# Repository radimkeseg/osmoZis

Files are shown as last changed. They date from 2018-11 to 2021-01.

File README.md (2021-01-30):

# OsmoZis v2 - osmóza - neinvazivní vysoušení vlhkého zdiva

... in other languages [english](README.en.md)

Potřebujete se zbavit vzlínající vlhkosti ve vašem domě? Typicky u starého domu s problematickou izolací základů?

Bez zbytečných průtahů a přílišné teorie, je jistá šance, že zařízení, které je zde popsané Vám může pomoci.
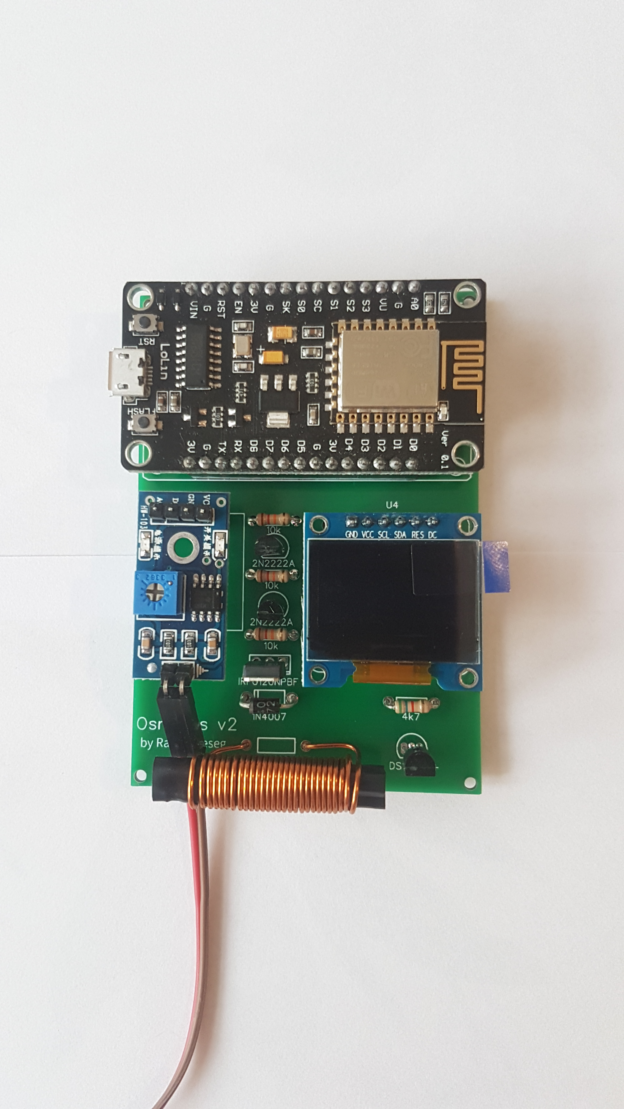
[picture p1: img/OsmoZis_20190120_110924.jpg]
OsmoZis v2


# Jak to funguje?
Zjednodušeně řečeno, toto zařízení generuje nízko frekvenční špičky, které eliminují síly které umožňuje vodnímu roztoku ve zdi překonat gravitaci a vyhrát nad silou, které způsobuje vzlínání, a voda se vrátí zpět do země.

Může to znít jako kouzlo, nicméně experimentálně byla funkčnost úspěšně ověřena.

Pokud se chcete dozvědět více detailů od expertů, určitě najdete na internetu spoustu článku a videí které by Vám mohli pomoci porozumět principu elektro-osmozy. Zajímavé video může být například v následujícím odkazu https://www.youtube.com/watch?v=hDw9_C7s-Mk.

# Je možné taková zařízení koupit?
Samozřejmě že ano, jen hledejte OSMO-něco ... jen jsou tato zařízení příliš drahá a jediné, jak člověk pozná že něco dělají je svítící dioda bez další možnosti, jak si průběžně ověřit, že zařízení funguje.

Toto je levné zařízení, které stojí jen zlomek ceny (asi 200 - 500kč za součástky dle toho, kde je koupíte) naproti tomu co je nabízeno na trhu (20000 - 50000 kč), ale poskytuje mnohem více funkcí:
* na displeji je možné vidět aktuální vlhkost
* dále i aktuální teplotu
* zařízení se dá připojit na wifi
  * kde dále vidíte jeho adresu
  * a aktuální čas
* s dalšími nastaveními
  * časová zóna
  * a odesílání dat na cloud (www.thinkgspeak.com) kde můžete vidět grafy vlhkosti a teploty online každý 10 minut standardně (nebo si interval nastavit dle osobních preferencí)

# Co potřebuji na to si zařízení vyrobit?
v adresáři ["img"](img), najdete návrh obvodu zařízení, dále výrobní data pro desku a další obrázky, které vám pomohou celé zařízení vytvořit.

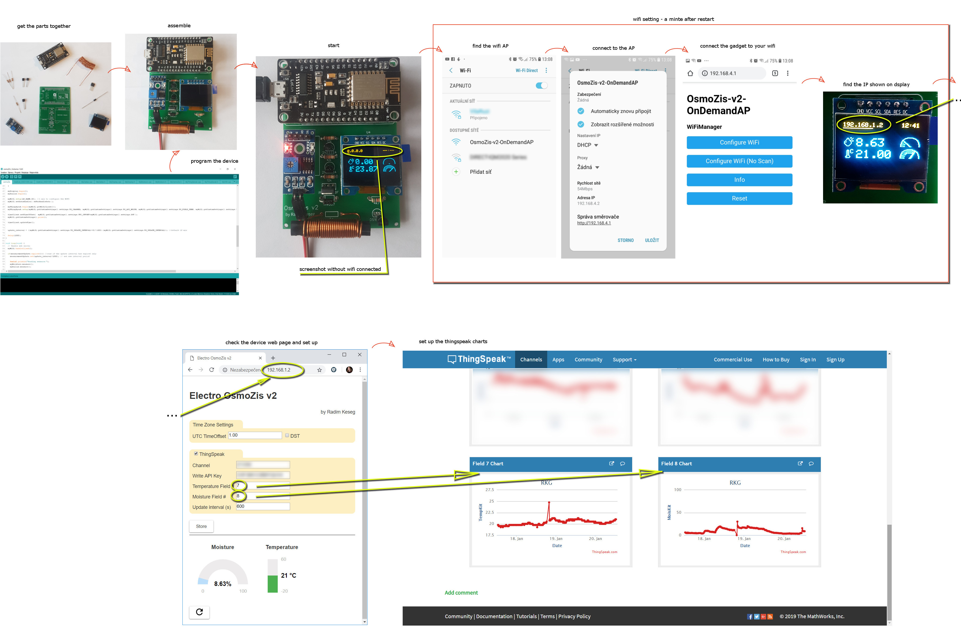
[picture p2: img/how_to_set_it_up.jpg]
setup


# Jak zařízení oživit?
v tomto adresáři najdete kód programu, na který se můžete podívat a případně jej upravit, pokud nechcete jen jej nahrajte do ESP přímo.

Pokud chcete zkoumat kód, je třeba stáhnout některé další knihovny, jejichž seznam najdete níže.

1. <OneWire.h> 
2. <DallasTemperature.h>

3. <SPI.h>
4. <Wire.h>
5. <Adafruit_GFX.h>
6. "Adafruit_SSD1306.h"

7. <Interval.h>
8. <ThingSpeak.h>

9. <WifiManager.h> (tzapo)

10. ESP8266 desku a knihovny k ní

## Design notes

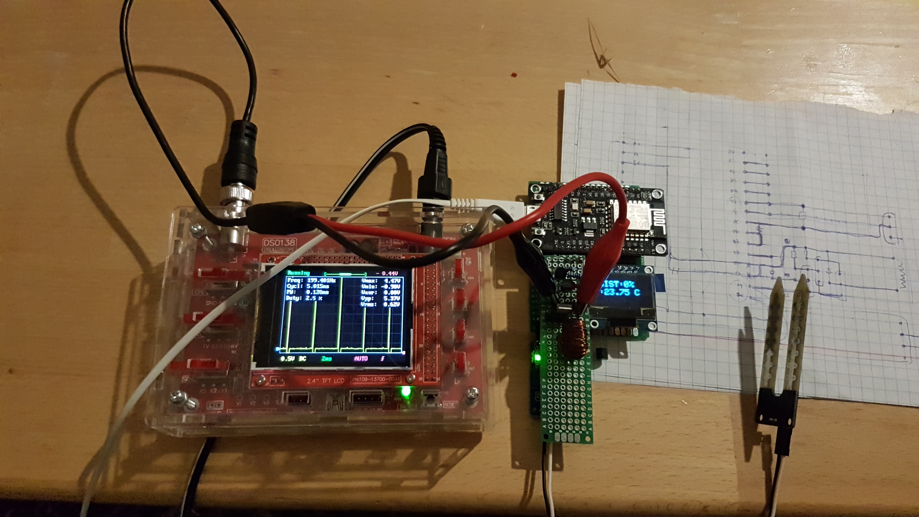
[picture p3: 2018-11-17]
img/prototype_20181117_184112.jpg

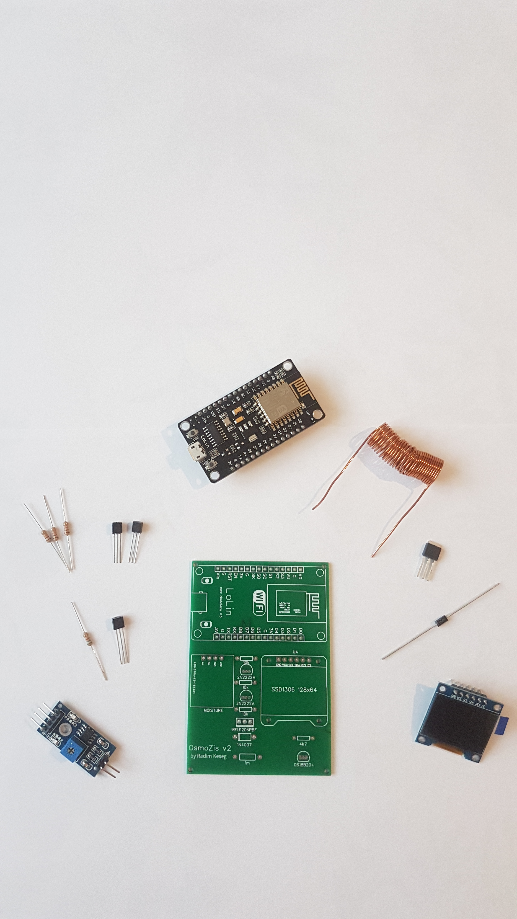
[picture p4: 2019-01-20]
img/OsmoZis_20190120_093138.jpg

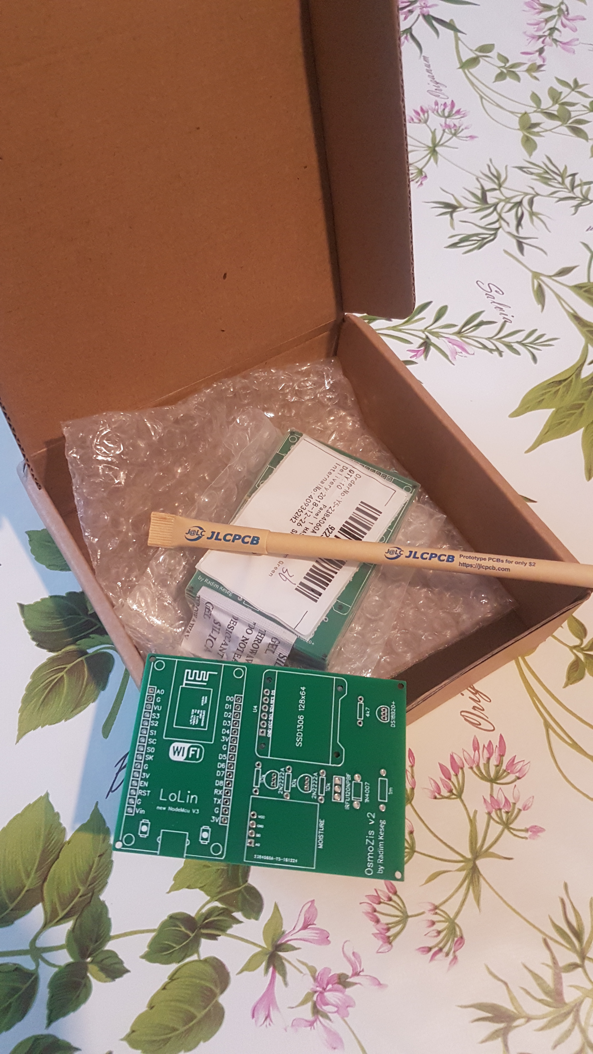
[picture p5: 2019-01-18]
img/JLCPCB_20190118_084525.jpg

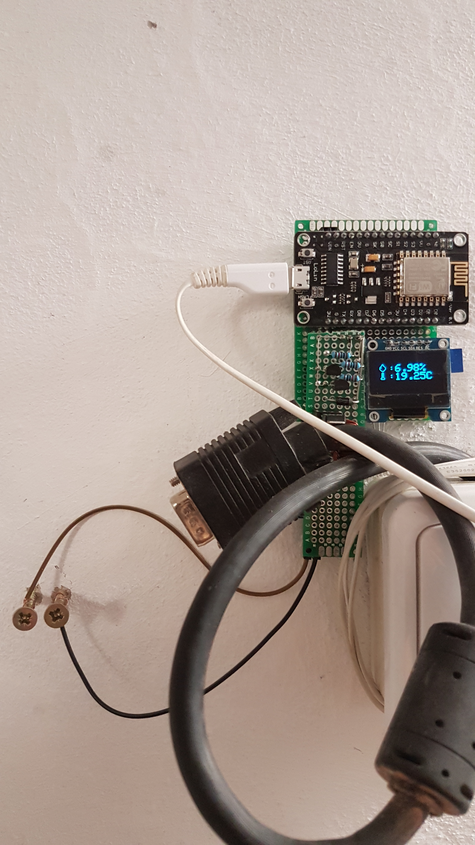
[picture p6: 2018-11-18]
img/prototype_20181118_135021.jpg

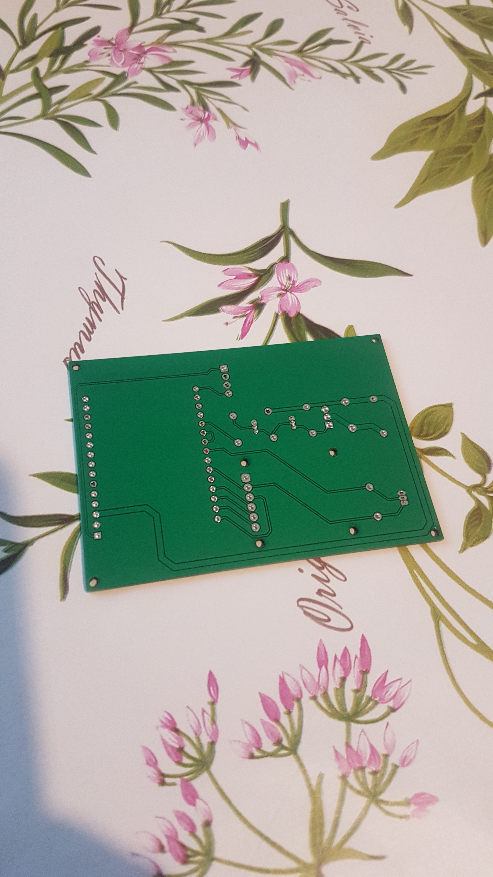
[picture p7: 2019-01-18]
img/JLCPCB_20190118_084754.jpg

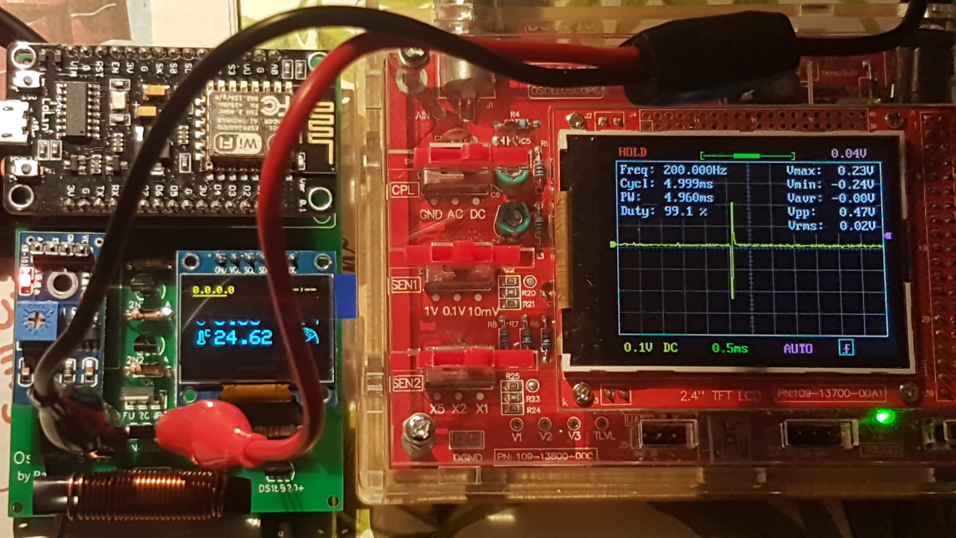
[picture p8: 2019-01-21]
img/short_duty_cycle.jpg

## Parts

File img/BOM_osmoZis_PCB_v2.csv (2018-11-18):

ID | Name | Designator | Footprint | Quantity | Manufacturer Part | Manufacturer | Supplier | Supplier Part | Mounted
1 | NODEMCU_V1_ESP12E | U1 | ESP12E_DEVKIT-V1 | 1 | ? |  |  |  | Yes
2 | DS18B20+ | U3 | TO-92(TO-92-3) | 1 | DS18B20+ | MAXIM | LCSC | C9753 | Yes
3 | 4k7 | R1 | AXIAL-0.3 | 1 | ? |  |  |  | Yes
4 | 10k | R2,R3,R4 | AXIAL-0.3 | 3 | ? |  |  |  | Yes
5 | 2N2222A | Q1,Q2 | TO-92 | 2 | ? |  |  |  | Yes
6 | IRFU120NPBF | Q3 | TO-251(I-PAK) | 1 | IRFU120NPBF | IR | LCSC | C3025 | Yes
7 | 1N4007 | D1 | DO-41 | 1 | 1N4007 | STARSEA | LCSC | C84641 | Yes
8 | 1m | L1 | AXIAL-0.4 | 1 | ? |  |  |  | Yes
9 | breakout | MOISTURE | SPARKFUN SHT15 | 1 | ? |  | SparkFun | 12587 | Yes
10 | SSD1306_6PIN | U4 | SSD1306_6_PIN | 1 | New SchematicLib |  |  | undefined | Yes

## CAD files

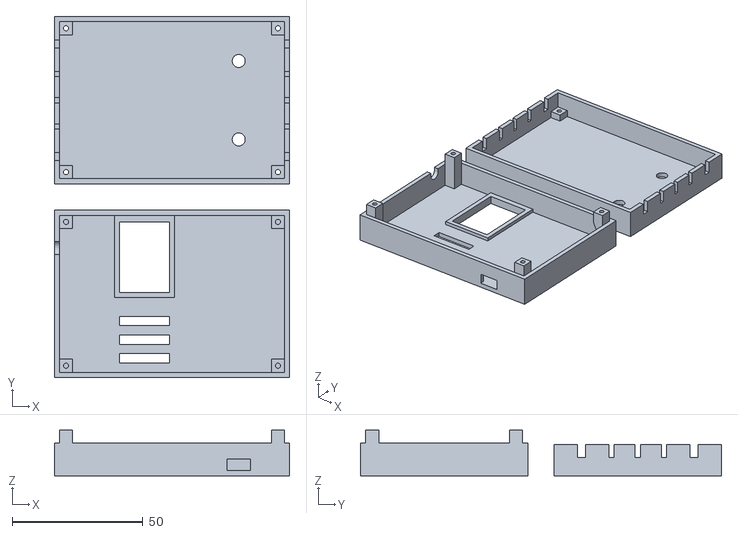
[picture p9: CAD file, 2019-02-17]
img/Osmozis V2.1.stl
90.0 x 138.0 x 17.5

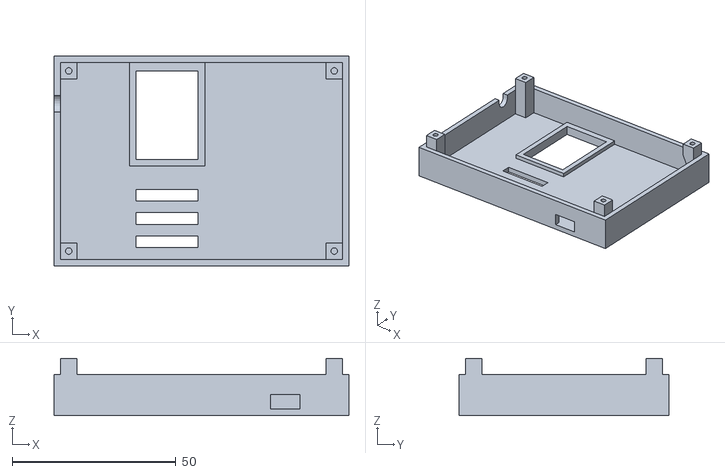
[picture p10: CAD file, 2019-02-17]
img/Osmozis V2.1 top.stl
90.0 x 64.0 x 17.5

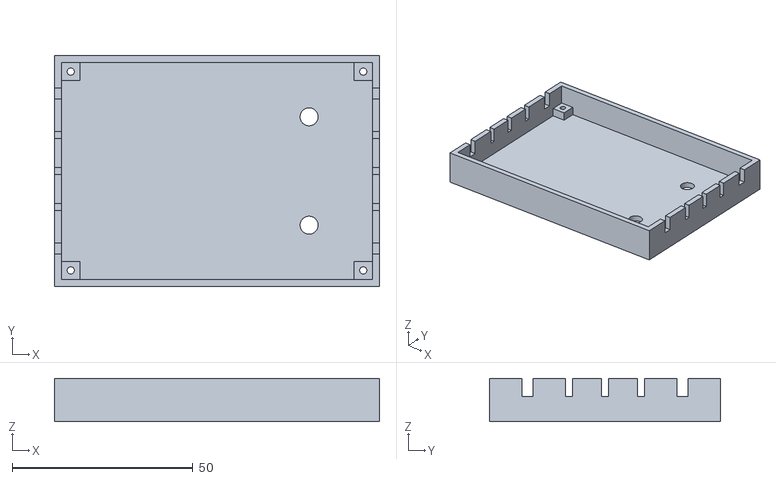
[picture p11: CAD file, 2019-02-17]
img/Osmozis V2.1 bottom.stl
90.0 x 64.0 x 12.0

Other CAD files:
img/Osmozis V2.1.skp

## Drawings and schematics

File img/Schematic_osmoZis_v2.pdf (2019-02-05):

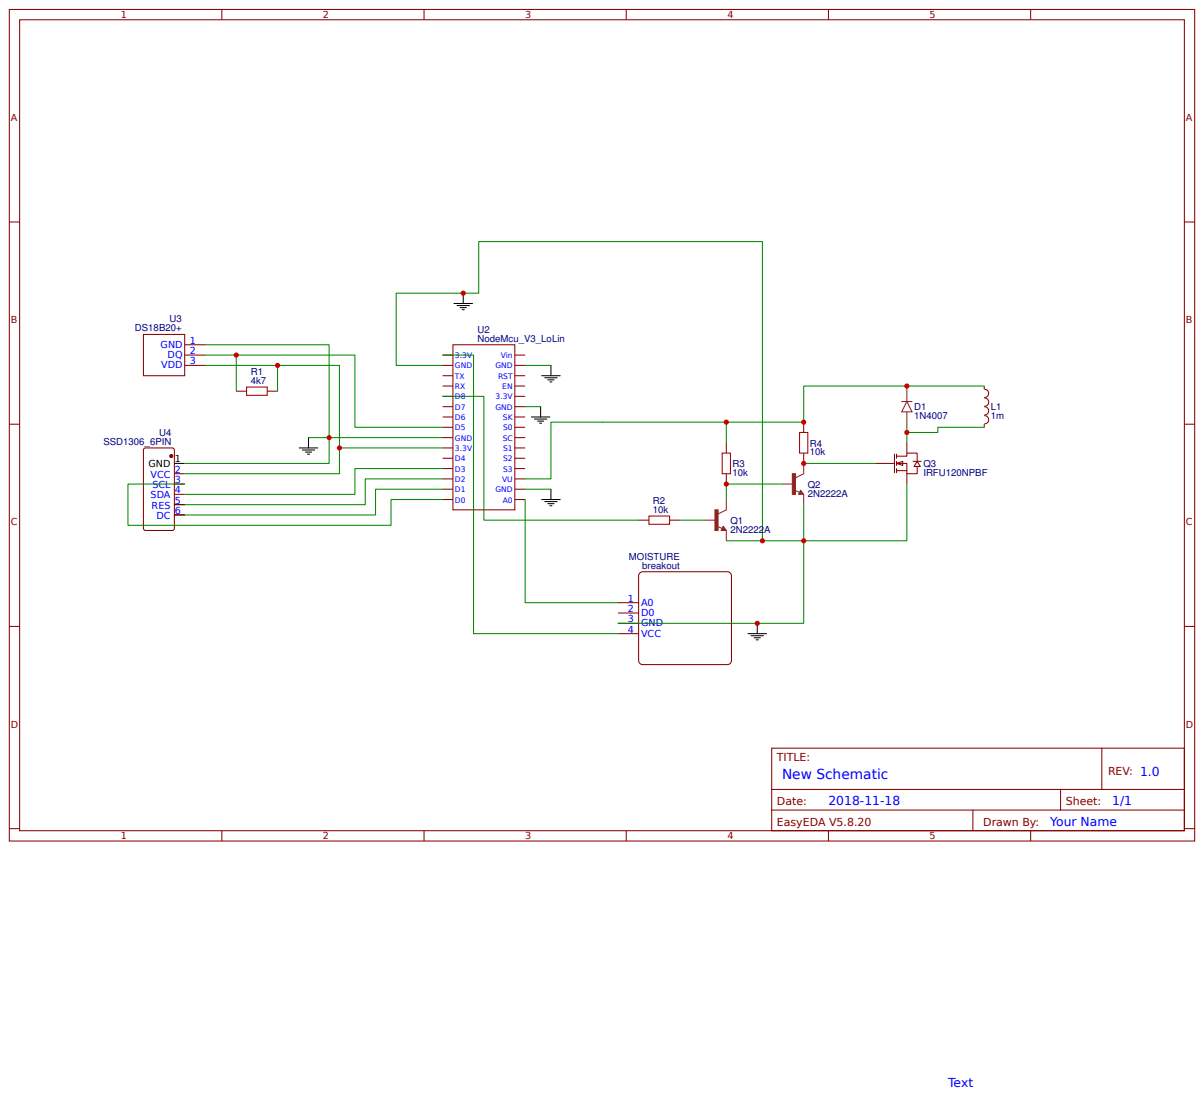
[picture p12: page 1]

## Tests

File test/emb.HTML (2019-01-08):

# Electro OsmoZis v2

by Radim Keseg

Time Zone Settings

UTC TimeOffset | | DST

ThingSpeak

Channel
Write API Key
Temperature Field #
Moisture Field #
Update interval(s)

### Moisture

### Temperature

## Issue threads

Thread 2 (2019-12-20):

Coil

kamarat, 2019-12-20:
Chcel by som sa opýtať, aká dôležitá je presnosť cievky L1. Ak som to správne pochopil, cievka má mať hodnotu 1 mH. Mohli by ste mi prosím poradiť, aké komponenty ste použili na výrobu cievky vy (drôt, priemer a dĺžka vinutia, jadro ...)? Ďakujem.

I would like to ask how important the accuracy of the L1 coil is. If I understood it correctly, the coil would have a value 1 mH. Could you please advise what components you used to make the coil (wire, diameter and length of winding, core ...)? Thank.

Chlebik-bit, 2020-10-30:
Cívka by mě také zajímala. Pro zajímavost - v komerčním přístroji Hydropol je prý cívka z drátu 2.5mm o 160 závitech.

naro, 2021-04-11:
Mám připravenou a funkční desku a cívka je poslední část, co mi chybí.
Podle obrázku v img odhaduji cívku tak na 1cm průměr a 3cm délku s 28mi závity. Podle výpočtu by taková cívka měla indukčnost 2.23uH což je řádově méně, než ve schématu.

Mohu se zeptat jakou cívku jste tedy použili a jestli máte nějaké reálné zkušenosti s provozem?

murcik, 2021-04-11:
Ahoj,
 
co sa tyka vykonovej casti, inspiroval som sa podla:
 
http://www.zibynet.cz/clanky-informace/elektroosmoza-ii
 
cievku mam na feritovej tycke 1cm priemer a dlzka 20cm - indukcnost 23mH
dostavam impulzy pri 200 Hz a dlzke cca 5% - okolo 900V pri napajani 24V
 
zatial to funguje v garazi. Cez zimu som nevidel velky pokrok, ale teraz uz je stena suchsia a vytvorili sa soli na stenach.
uvidim ako to bude pokracovat.
 
Marian
 
 
______________________________________________________________
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
 
Mám připravenou a funkční desku a cívka je poslední část, co mi chybí.
 Podle obrázku v img odhaduji cívku tak na 1cm průměr a 3cm délku s 28mi závity. Podle výpočtu by taková cívka měla indukčnost 2.23uH což je řádově méně, než ve schématu.
Mohu se zeptat jakou cívku jste tedy použili a jestli máte nějaké reálné zkušenosti s provozem?
—
You are receiving this because you are subscribed to this thread.
Reply to this email directly, view it on GitHub <https://github.com/radimkeseg/osmoZis/issues/2#issuecomment-817263102>, or unsubscribe <https://github.com/notifications/unsubscribe-auth/AQLHYUM6WQJWDDW2TLL72VLTIFFIFANCNFSM4J52RMFA>.

robacik, 2021-04-12:
Ahoj.
Chcel by som sa opytat na suciastku  MOISTURE SPARKFUN SHT15, neviem to nikde na internete najst (mozem poprosit link alebo cely nazov).
Podla vsetkeho je to tepelne/vlhkost cidlo.
dakujem

naro, 2021-04-12:
Použil jsem https://www.laskarduino.cz/arduino-senzor-vlhkosti-pudy/

robacik, 2021-04-12:
Dakujem, da sa to najst pod : Glyduino FC-28 Soil Hygrometer Humidity Detection Module Moisture Water Sensor for Arduino

murcik, 2021-04-12:
je to jedno, pretoze ta elektronika je iba comparator na DO (LED)
v skutocnosti ked vyuzivas analog, tak je to to iste ako ked do steny navrtas v srubky a ce odpor privedies 5V a potom cez AI prepocitas prud na hodnotu %
 
______________________________________________________________
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
 
Dakujem, da sa to najst pod : Glyduino FC-28 Soil Hygrometer Humidity Detection Module Moisture Water Sensor for Arduino
—
You are receiving this because you commented.
Reply to this email directly, view it on GitHub <https://github.com/radimkeseg/osmoZis/issues/2#issuecomment-817630640>, or unsubscribe <https://github.com/notifications/unsubscribe-auth/AQLHYUOXGQL7MOBSDNJR52LTIKZUNANCNFSM4J52RMFA>.

murcik, 2021-04-12:
je to jedno, pretoze ta elektronika je iba comparator na DO (LED)
v skutocnosti ked vyuzivas analog, tak je to to iste ako ked do steny navrtas v srubky a ce odpor privedies 5V a potom cez AI prepocitas prud na hodnotu %
 
______________________________________________________________
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
 
Použil jsem https://www.laskarduino.cz/arduino-senzor-vlhkosti-pudy/ <https://www.laskarduino.cz/arduino-senzor-vlhkosti-pudy/>
—
You are receiving this because you commented.
Reply to this email directly, view it on GitHub <https://github.com/radimkeseg/osmoZis/issues/2#issuecomment-817606034>, or unsubscribe <https://github.com/notifications/unsubscribe-auth/AQLHYUPUVI5QPKN6GXOA3GLTIKVYBANCNFSM4J52RMFA>.

robacik, 2021-04-13:
Ahoj.

Este jednu otazocku mam.

Ako to cele napajate, predpokladam, ze to nie je cez USB rozhranie ?

Pouzivate Power Supply Module 3.3V/5V ktory privediete na +3.3V  -> 3V  a -> G na chrobaka  ESP8266 ?

Dakujem

murcik, 2021-04-14:
vykonova cast je na 24V a arduino napajam 5V  (samotna doska ma regulator na 3,3V)
 
v podstate z tochto projektu mam iba software ktory aj tak som asi na 40% pozmenil
 
______________________________________________________________
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
 
Ahoj.
Este jednu otazocku mam.
Ako to cele napajate, predpokladam, ze to nie je cez USB rozhranie ?
Pouzivate Power Supply Module 3.3V/5V ktory privediete na +3.3V -> 3V a -> G na chrobaka ESP8266 ?
Dakujem
—
You are receiving this because you commented.
Reply to this email directly, view it on GitHub <https://github.com/radimkeseg/osmoZis/issues/2#issuecomment-818752700>, or unsubscribe <https://github.com/notifications/unsubscribe-auth/AQLHYUJFJPUJFID6SJB6TF3TIRD65ANCNFSM4J52RMFA>.

xcusso, 2023-06-29:
Hi,
I'm trying to construct this device. Can you let me know the voltage used in the pulse section 24V or 5V and the coil used?
And if you have successful experience about it?
Many thanks in advance.

Xavi

PetrBernard, 2023-10-11:
Ahoj, hloupý dotaz, kam připojit napájení výkonové části 24V ? Na prostřední nožičku mosfetu ??

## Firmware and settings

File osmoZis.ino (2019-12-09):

/*********************************************************************
OsmoZis by Radim Keseg
*********************************************************************/


#include "MyMoisture.h"
MyMoisture myMoisture;

#include "MyDallas.h"
MyDallas myDallas;

#include "MyThingSpeak.h"
MyThingSpeak myThingSpeak;

#include "MyDisplay.h"
MyDisplay myDisplay;

#include "MyWifi.h"
MyWifi myWifi;

#include "TimeClient.h"
TimeClient timeClient(1);

#include "MyOsmoZis.h"

static String stFncHandleData(){
  String res;
  res = "{\"temp\":\"";
  res += myDallas.getLastMeasured();
  res += "\",\"mois\":\"";
  res += myMoisture.getLastMeasured();
  res += "\"}";
  return res;
}

Interval measurementUpdate;
long update_interval = 600*1000; //default 10 min

#define TRIGGER_PIN 0
#define AP_NAME "OsmoZis-v2"

void setup()   {                
  Serial.begin(9600);

  pinMode(MEASURING, OUTPUT);
  
  setupOsmoZis();  

  myDisplay.begin();
  myDisplay.write_intro(true);

  pinMode(TRIGGER_PIN, OUTPUT); //set the trigger pin to HIGH as preset
  digitalWrite(TRIGGER_PIN, HIGH);
  delay(200);

  pinMode(TRIGGER_PIN, INPUT); //when flash pressed get to wifi config portal
  for(int i=0; i<100; i++){
    if ( digitalRead(TRIGGER_PIN) == LOW ) {
      Serial.println("manual config portal triggered ");
      myDisplay.write_intro(true);
      myWifi.forceManualConfig((String(AP_NAME)+"-OnDemandAP").c_str());
      Serial.println("connecting again ...)");
    }
    delay(50);
  }


  myDisplay.begin();
  myDisplay.write_intro(false);

  myDallas.begin();

  myWifi.setup(AP_NAME,60); //1 min to configure the WIFI 
  myWifi.setDataHandler( stFncHandleData );

  myThingSpeak.begin(myWifi.getWifiClient());
  myThingSpeak.setup(myWifi.getCustomSettings().settings.TS_CHANNEL, myWifi.getCustomSettings().settings.TS_API_WRITE, myWifi.getCustomSettings().settings.TS_FIELD_TEMP, myWifi.getCustomSettings().settings.TS_FIELD_MOIS, myWifi.getCustomSettings().settings.TS_UPDATE_INTERVAL);
  
  timeClient.setTimeOffset(  myWifi.getCustomSettings().settings.UTC_OFFSET+myWifi.getCustomSettings().settings.DST );
  myWifi.getCustomSettings().print();
  
  timeClient.updateTime();


  update_interval = ((myWifi.getCustomSettings().settings.TS_UPDATE_INTERVAL<=0)?(600):(myWifi.getCustomSettings().settings.TS_UPDATE_INTERVAL)); //default 10 min
  
  delay(1000);
}

void loop(void) {
  // Handle web server
  myWifi.handleClient();
  
  if(measurementUpdate.expired()){ //read if the update interval has expired only
    measurementUpdate.set(update_interval*1000); // set new interval period 

    Serial.println("Reading sensors:");
    myMoisture.measure();
    myDallas.measure();
    
    myDisplay.clearDisplay(); 
  
    myDisplay.write_IP(0,1, myWifi.getIP().c_str());
    myDisplay.write_time(127,1, timeClient.getFormattedTimeShort().c_str());
    
    myDisplay.write_moisture( 0,24,  myMoisture.getLastMeasured());
      myDisplay.write_gauge( 96,23, myMoisture.getLastMeasured(),false,0,30);
    myDisplay.write_temp(     0,44,  myDallas.getLastMeasured());
      myDisplay.write_gauge( 96,43, myDallas.getLastMeasured(),false,0,30);
  
    myDisplay.showDisplay();

    if(myWifi.getCustomSettings().settings.THINGSPEAK){ //write to thingspeak
      if(myWifi.isConnected()){
        myThingSpeak.write(myDallas.getLastMeasured(),myMoisture.getLastMeasured());
      }
    }
  
  }

  myDisplay.clear_rect(0,0,127,9);
  myDisplay.write_IP(0,1, myWifi.getIP().c_str());
  myDisplay.write_time(127,1, timeClient.getFormattedTimeShort().c_str());
  myDisplay.write_progress(0,10,127,1,measurementUpdate.elapsed()/1000,false,0,measurementUpdate.getTimeout()/1000);
  //Serial.print("time elapsed: ");Serial.print(measurementUpdate.elapsed()/1000);Serial.print("time remains: ");Serial.println(measurementUpdate.remains()/1000);
  myDisplay.showDisplay();
  
  //Serial.print(".");
  delay(1000);
}

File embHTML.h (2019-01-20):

/**The MIT License (MIT)

Copyright (c) 2019 by Radim Keseg

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
THE SOFTWARE IS PROVIDED "AS IS", WITHOUT WARRANTY OF ANY KIND, EXPRESS OR
IMPLIED, INCLUDING BUT NOT LIMITED TO THE WARRANTIES OF MERCHANTABILITY,
FITNESS FOR A PARTICULAR PURPOSE AND NONINFRINGEMENT. IN NO EVENT SHALL THE
AUTHORS OR COPYRIGHT HOLDERS BE LIABLE FOR ANY CLAIM, DAMAGES OR OTHER
LIABILITY, WHETHER IN AN ACTION OF CONTRACT, TORT OR OTHERWISE, ARISING FROM,
OUT OF OR IN CONNECTION WITH THE SOFTWARE OR THE USE OR OTHER DEALINGS IN THE
SOFTWARE.
*/

#include "Arduino.h" //not sure why but here it is needed

const char PAGE_INDEX[] PROGMEM = R"=====(
<!DOCTYPE html>
<html>
<head>
  <meta charset="utf-8">
  <title>Electro OsmoZis v2</title>


  <style>
.rGauge {
  width: 200px;
  height: 145px;
}
.rGauge-base {
  stroke: #edebeb;
  fill: none;
}
.rGauge-progress {
  fill: none;
  transition: 0.5s;
}
.rGauge-val {
  font-weight: 700;
  font-size: 1.3em;
}
.rGauge-min-val, .rGauge-max-val {
  fill: #b3b3b3;
}
.vGauge {
  width: 145px;
  height: 145px;
}
.vGauge-base {
  fill: #edebeb;
}
.vGauge-progress {
  transition: 0.5s;
}
.vGauge-val {
  font-weight: 700;
  font-size: 1.3em;
}
.vGauge-min-val, .vGauge-max-val {
  fill: #b3b3b3;
} 
  </style>
  <style>
body {
  margin: 0;
  padding: 20px;
  font-family: Helvetica,Arial,sans-serif;
  font-size: 14px;
  line-height: 1.42857143;
  color: #333;
  background-color: #fff;
}
.gauge-section {
  display: inline-block;
  text-align: center;
}
.gauge-section h3 {
  margin-bottom: 0;
}
.gauge {
  display: inline-block;
}
.actions {
  margin-top: 15px;
}
.btn {
  color: #333;
  border: 0;
  border-radius: 3px;
  box-shadow: 0px 1px 3px #666666;
  background: #fff;
  padding: 10px 20px 10px 20px;
  text-decoration: none;
  cursor: pointer;
}
.btn-icon {
  padding: 2px 15px 2px 15px;
}
.btn:active {
  background: #dddddd;
  text-decoration: none;
} 

</style>
 
<style>
hr {
  border: 0px;
  border-bottom: 1px solid black;
}
.btn-group {
  border: 0px solid black;
  -webkit-border-radius: 0px 10px 10px 10px;
  border-radius: 0px 10px 10px 10px; 
  background-color: #feefc3;
  padding: 5px;
  margin-bottom: 20px;
}
checkbox input:before {
  content: '';
  background: #fff;
  display: block;
  width: 10px;
  height: 10px;
  border: 1px solid black;
  margin-left: 0px;
}

input{
  transition: 0.5s;
}

label{
  display: block;
  width:100px;
  height: 25px;
  display: table-cell;
  vertical-align: bottom;
  white-space: nowrap;
}
label.title{
  width:150px;
  padding-left: 10px;
  border-radius: 10px 10px 0px 0px; 
  background-color: #feefc3;
}
 </style>
</head>

<body>
<h1>Electro OsmoZis v2</h1>
<p style='text-align: right'>by Radim Keseg</p>

<form method='post' action='offset'>

<label class='title'>Time Zone Settings</label>
<div class='btn-group'>
<table>
<tr><td><label>UTC TimeOffset</label></td><td><input id='_timeoffset' name='_timeoffset' length=5 pattern='^[0-9-\\.]{1,5}$' required value='{timeoffset}'></td>
<td colspan='2'><label><input id='_dst' name='_dst' type='checkbox' {dst}>DST</label></td></tr>
</table>
</div>

<label class='title'><input id='_ts' name='_ts' type='checkbox' {ts}>ThingSpeak</label>
<div class='btn-group'>
<table>
<tr><td><label>Channel</label></td><td><input id='_ts_channel' name='_ts_channel' length=16 pattern='^[0-9]{1,16}$' required value='{ts_channel}'></td></tr>
<tr><td><label>Write API Key</label></td><td><input id='_ts_write_api_key' name='_ts_write_api_key' length=16 pattern='^[0-9a-zA-Z]{16}$' required value='{ts_write_api_key}'></td></tr>
<tr><td><label>Temperature Field #</label></td><td><input id='_ts_field_temp' name='_ts_field_temp' length=1 pattern='^[0-8]{1}$' required value='{ts_field_temp}'></td></tr>
<tr><td><label>Moisture Field #</label></td><td><input id='_ts_field_mois' name='_ts_field_mois' length=1 pattern='^[0-8]{1}$' required value='{ts_field_mois}'></td></tr>
<tr><td><label>Update interval (s)</label></td><td><input id='_ts_update_interval' name='_ts_update_interval' length=4 pattern='^[0-9]{1,16}$' required value='{ts_update_interval}'></td></tr>
</table>
</div>

<input type='submit' value='Store' class='btn'></form>

<hr/>

  <div>
    <div class="gauge-section">
      <h3>Moisture</h3>
      <div id="mois" class="gauge"></div>
    </div>
    <div class="gauge-section">
      <h3>Temperature</h3>
      <div id="temp" class="gauge"></div>
    </div>
  </div>
  <div class="actions">
    <button id="refresh" class="btn btn-icon">
      <svg height="30" viewBox="0 0 24 24" width="30">
          <path d="M17.65 6.35C16.2 4.9 14.21 4 12 4c-4.42 0-7.99 3.58-7.99 8s3.57 8 7.99 8c3.73 0 6.84-2.55 7.73-6h-2.08c-.82 2.33-3.04 4-5.65 4-3.31 0-6-2.69-6-6s2.69-6 6-6c1.66 0 3.14.69 4.22 1.78L13 11h7V4l-2.35 2.35z"/>
          <path d="M0 0h24v24H0z" fill="none"/>
      </svg>
    </button>
  </div>

  <script>
function createRadGauge(id, minVal, maxVal, unit) {
  function polarToCartesian(centerX, centerY, radius, rad) {
    return {
      x: centerX + (radius * Math.cos(rad)),
      y: centerY + (radius * Math.sin(rad))
    };
  }
  
  function arc(x, y, radius, val, minVal, maxVal){
      var start = polarToCartesian(x, y, radius, -Math.PI);
      var end = polarToCartesian(x, y, radius, -Math.PI*(1 - 1/(maxVal-minVal) * (val-minVal)));
  
      var d = [
          "M", start.x, start.y, 
          "A", radius, radius, 0, 0, 1, end.x, end.y
      ].join(" ");
  
      return d;       
  }

  var tmpl = 
  '<svg class="rGauge" viewBox="0 0 200 145">'+ 
    '<path class="rGauge-base" id="'+id+'_base" stroke-width="30" />'+ 
    '<path class="rGauge-progress" id="'+id+'_progress" stroke-width="30" stroke="#1565c0" />'+ 
    '<text class="rGauge-val" id="'+id+'_val" x="100" y="105" text-anchor="middle"></text>'+  
    '<text class="rGauge-min-val" id="'+id+'_minVal" x="40" y="125" text-anchor="middle"></text>'+  
    '<text class="rGauge-max-val" id="'+id+'_maxVal" x="160" y="125" text-anchor="middle"></text>'+  
  '</svg>';

  document.getElementById(id).innerHTML = tmpl;
  document.getElementById(id+'_base').setAttribute("d", arc(100, 100, 60, 1, 0, 1));
  document.getElementById(id+'_progress').setAttribute("d", arc(100, 100, 60, minVal, minVal, maxVal));
  document.getElementById(id+'_minVal').textContent = minVal;
  document.getElementById(id+'_maxVal').textContent = maxVal;

  var gauge = {
    setVal: function(val) {
      val = Math.max(minVal, Math.min(val, maxVal));
      document.getElementById(id+'_progress').setAttribute("d", arc(100, 100, 60, val, minVal, maxVal));
      document.getElementById(id+'_val').textContent = val + (unit !== undefined ? unit: '');
      return gauge;
    },
    setColor: function(color) {
       document.getElementById(id+'_progress').setAttribute("stroke", color);
       return gauge;
    }
  }
  
  return gauge;
}
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

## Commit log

2018-11-18 schematics and Gerber added
    [BOM_osmoZis_PCB_20181118134731.csv]
2018-11-18 gerber update
2018-11-19 Gerber update - corrected silk screen
2018-11-19 schematicsupgraded by GND net
2018-11-19 still ugly but with fixed interrupt issue
2018-11-19 gerber preview
2018-12-23 PCB update
2018-12-25 manual vs auto wifi config fixed
    [MyDisplay.h, MyWifi.cpp, osmoZis.ino]
2018-12-25 debug print removed
2019-01-18 pwm generator freq updated
2019-01-18 JLCPCB boards
2019-02-05 circuitry and PCB upgraded
    [BOM_osmoZis_PCB_v2.csv]
2019-02-17 3D box
    [Osmozis V2.1 bottom.stl, Osmozis V2.1 top.stl, Osmozis V2.1.skp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]
